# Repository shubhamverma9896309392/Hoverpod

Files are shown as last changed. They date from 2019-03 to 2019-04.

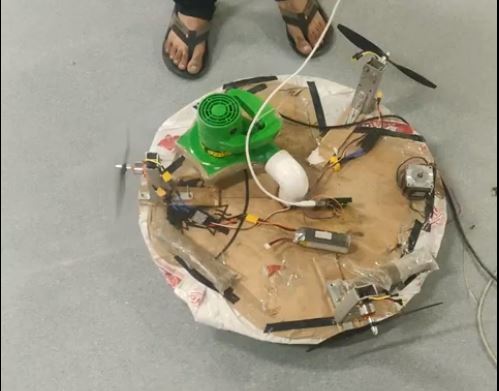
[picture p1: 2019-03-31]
Images and Videos/Images/Electronics.JPG

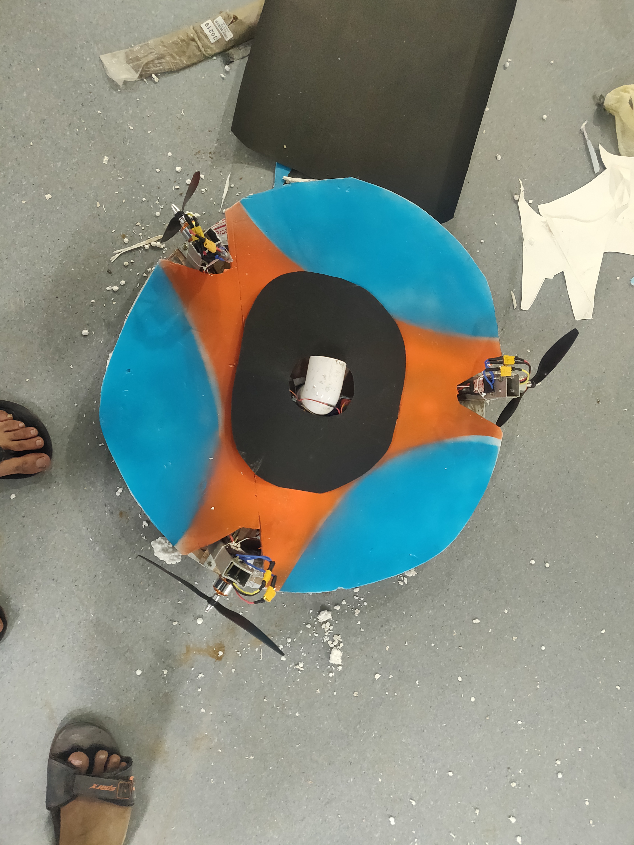
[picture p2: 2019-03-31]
Images and Videos/Images/Final1.jpg

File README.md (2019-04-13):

## Hoverpod
_A vehicle that hovers over land as well as water_
bot1
## Abstract
The idea of this project is to make a vehicle that hovers over water and land.The team is working on this project for three months and team was successful in making a hoverpod that can lift upto 15 kgs.Moreover it can be controlled by an android app with aid of bluetooth.

## Motivation
Our Bot can move efficiently on any plane surface, the almost frictionless design reduces wear and tear and saves energy the versatility of a hovercraft is well exploited by the US NAVY for shipment, which was our motivation, where we tried to further improve the control mechanism.

## Electronics Aspect of the Design 
1. Electronic Component Used
     1. BLDC Motors
     2. Arduino UNO
     3. Batteries
     4. Air blower 
     5. Bluetooth module HC-05
     6. ESCs
     7. Android device
     8. Connecting wires and jumpers
2. 2. Arduino Uno was used for motion of BLDC motors as well as to connect bluetooth module.
3. A bluetooth module was used for transmission of commands from android device to our hoverpod.  
4. All the BLDC motors were powered through Li-Po 11.1V dc battery.

## Mechanical Aspect of the Design
It stands on a circular wooden board and comprises of 3 BLDC motors and a blower. Below it it consists of an inflated air tube which allows it to levitate over ground.

## Cost Structure
|COMPONENTS | COST(₹)|
|----|---|
|Android Device|10000|
|Blower|750|
|Arduino Uno|500|
|ESC motor driver(3)|1440|
|Bluetooth module|350|
|Voltmeter|160|
|BLDC motors(3)|1050|
|Li-Po battery(2)|2200|
|Other Components|2000|
|Total|18450|

##  Final Changes and Modification in design
The structure was inclined due to unhealthy weight balancing so we need to balance it. And also it required some error correction in steering it.

## Working
Air blower blows air in the tube which consists of small pores at the lower side of it so that it creates an air cushion over which structure can hover. It is controlled by 3 BLDC motors which helps to steer it. And BLDC is controlled through arduino with the aid of bluetooth module. 

 ## Limitations
 - It can lift only upto 15 kgs.
 - As friction is not present,it is a difficult to steer it.
 - Blower requires a high power input so it need to be connected through wire.
 ## Future Improvements
 - To make it wireless, by installing a bigger battery.
 - To make turning more efficient by using a Gyro sensor in conjunction with PID.
 - To increase weight lifting capability.

## Team Members

1. Pulkit Mundra
2. [Rishabh Sharma](https://github.com/rishabh0203iitr)
3. [Shubham Verma](https://github.com/shubhamverma989630)
## Mentors

1. Avdesh Ranwa
2. Raghav Dhingra

circuit

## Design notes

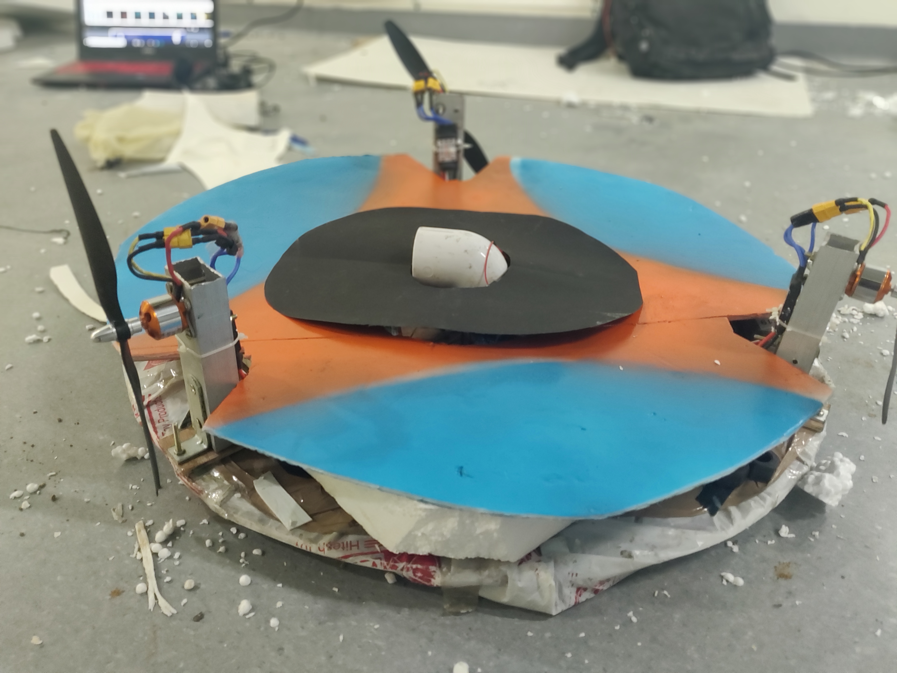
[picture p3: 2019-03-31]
Images and Videos/Images/Final2.jpg

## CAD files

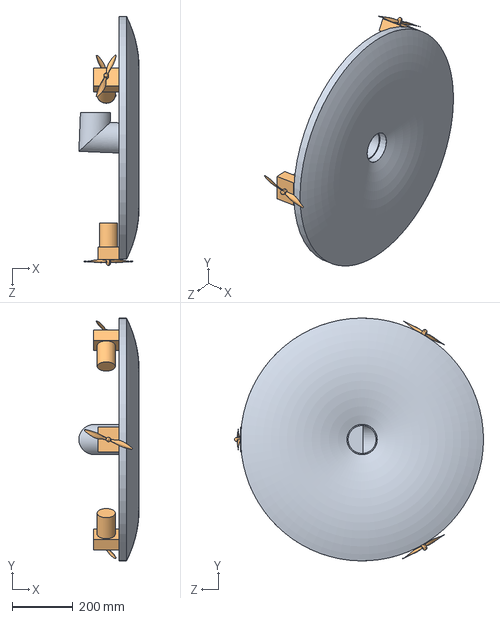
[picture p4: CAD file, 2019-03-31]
Mechanical Aspect/FINAL HOVERPOD.SLDASM
198.6 x 799.8 x 820.4 mm
hoverpod
Assem1 x 3

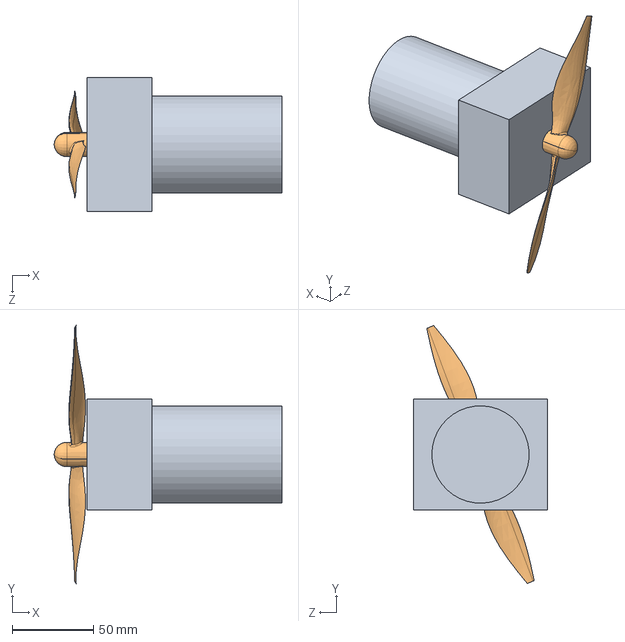
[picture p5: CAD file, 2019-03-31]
Mechanical Aspect/Assem1.SLDASM
140.4 x 159.0 x 82.7 mm
base
Propeller375

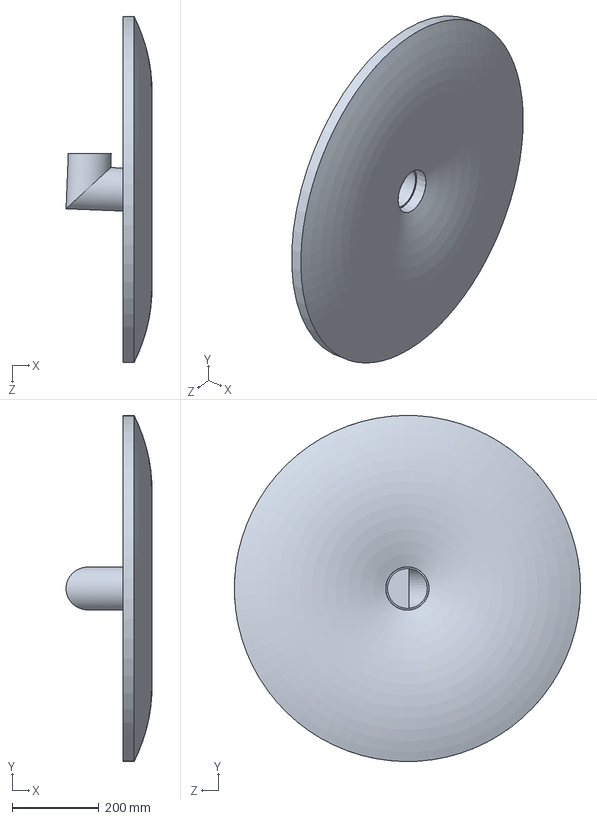
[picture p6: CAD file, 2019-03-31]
Mechanical Aspect/hoverpod.SLDPRT
198.6 x 799.8 x 799.6 mm

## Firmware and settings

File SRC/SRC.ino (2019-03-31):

#include <Servo.h>
Servo esc_signal1;
Servo esc_signal2;
Servo esc_signal3;
char command;

void setup()
{
  Serial.begin(9600);
  esc_signal1.attach(11);  //Specify here the pin number on which the signal pin of ESC is connected.
  esc_signal1.write(30);   //ESC arm command. ESCs won't start unless input speed is less during initialization.
  delay(3000);            //ESC initialization delay.

  esc_signal2.attach(10);  //Specify here the pin number on which the signal pin of ESC is connected.
  esc_signal2.write(30);   //ESC arm command. ESCs won't start unless input speed is less during initialization.
  delay(3000);     

  esc_signal3.attach(9);  //Specify here the pin number on which the signal pin of ESC is connected.
  esc_signal3.write(30);   //ESC arm command. ESCs won't start unless input speed is less during initialization.
  delay(3000);     
  
}

void loop()
{
while (Serial.available()==0){}

if(Serial.available()>0){
  command=Serial.read();
  }
  
  if(command=='P')
  {
    esc_signal1.write(0);
    esc_signal2.write(120);    //Vary this between 40-130 to change the speed of motor. Higher value, higher speed.
    esc_signal3.write(120);
    Serial.println(command);
    delay(15);
  }
  else if(command=='Q')
  {
    esc_signal1.write(120);
    esc_signal2.write(0);    //Vary this between 40-130 to change the speed of motor. Higher value, higher speed.
    esc_signal3.write(120);
    Serial.println(command);
    delay(15);
  }
  else if(command=='R')
  {
    esc_signal1.write(120);
    esc_signal2.write(120);    //Vary this between 40-130 to change the speed of motor. Higher value, higher speed.
    esc_signal3.write(0);
    Serial.println(command);
    delay(15);
  }
  else if(command=='A')
  {
    esc_signal1.write(0);
    esc_signal2.write(120);    //Vary this between 40-130 to change the speed of motor. Higher value, higher speed.
    esc_signal3.write(0);
    Serial.println(command);
    delay(15);
  }
  else if(command=='B')
  {
    esc_signal1.write(0);
    esc_signal2.write(0);    //Vary this between 40-130 to change the speed of motor. Higher value, higher speed.
    esc_signal3.write(120);
    Serial.println(command);
    delay(15);
  }
  else if(command=='C')
  {
    esc_signal1.write(120);
    esc_signal2.write(0);    //Vary this between 40-130 to change the speed of motor. Higher value, higher speed.
    esc_signal3.write(0);
    Serial.println(command);
    delay(15);
  }
  else if(command=='S')
  {
    esc_signal1.write(0);
    esc_signal2.write(0);    //Vary this between 40-130 to change the speed of motor. Higher value, higher speed.
    esc_signal3.write(0);
    Serial.println(command);
    delay(15);
  }

}
